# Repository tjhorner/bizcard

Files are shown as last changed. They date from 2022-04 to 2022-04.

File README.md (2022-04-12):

# PCBusiness Card



Hiya! Welcome to the documentation for my... business card? Yep, my business card. Which is also a PCB. Chances are you received one from me and are curious enough to scan the QR code on the back.

In these docs, you'll find information on the specs, how to flash it, which peripherals are onboard, how to do cool stuff with it, and (if you received a bare board) where to source the parts you'll need to assemble it. You'll also find the source KiCad project files for the schematic and board, as well as the source for the firmware that is installed by default. These are open source under CC-BY-SA 4.0 and MIT, so feel free to base your own designs on them.

## Directory Structure

- `docs`: Various documents about the project, including hardware info, flashing instructions, etc.
- `firmware`: Default firmware that ships with the board
- `pcb`: KiCad project files for the PCB

## Quick Start

If you want to check out all this board has to offer...

- Look at the docs for the [default firmware](docs/firmware.md). It goes in detail on what it does, and how you can connect to it to your computer via serial to enjoy the whole experience.
- Come back here to dive into the specs, then try your hand at [writing your own firmware](docs/flashing.md) (if you've programmed an Arduino before, it'll be a piece of cake).

After that, it's up to you! You can solder on some GPIO headers and connect whatever the heck you want and make it your own. Blinky Christmas lights? Sure! Doorbell? Why not! Pacemaker? Ok maybe not that. You have the full power of the RP2040 at your disposal, plus a hefty amount of flash you can use to store anything you want.

## Documentation

- [Bill of Materials](docs/bom.md)
- [Flashing Instructions](docs/flashing.md)
- [Schematic](docs/schematic.pdf)
- [FAQ](docs/faq.md)

## Bare Board Assembly

If you received a bare board, you can find the list of parts you will need (and links to where you can buy them) in the [bill of materials](docs/bom.md). At the moment, this assumes you know how to solder really small surface-mount parts (there are a couple of 0402 parts on there)! So this isn't really a beginner project, unfortunately. I might make a through-hole version in the future (or make the SMD pads bigger, I guess), so that it's easier for beginners, but right now you need to be really good at soldering very precisely.

If, for some reason, you really really want an assembled board, there are services out there that will do it for you. Just Google around for "SMT assembly service" and you'll find one. Or you could just ask me. Let me know what you plan to use it for, and if I have any assembled ones lying around I will gladly send one over for you to tinker with! You know how to reach me :)

## Specs

Here is a summary of the things on the board, but you can find more detailed info below:

- **Microcontroller**: [RP2040](https://www.raspberrypi.com/products/rp2040)
- **Flash**: 16MB [W25Q128JVS](http://www.winbond.com/resource-files/w25q128jv_dtr%20revc%2003272018%20plus.pdf)
- **Clock**: 12MHz [X322512MSB4SI](https://lcsc.com/product-detail/SMD-Crystal-Resonators_Yangxing-Tech-X322512MSB4SI_C9002.html) crystal
- **Connectivity**: USB-C 2.0
- **Peripherals**
  - Piezo Buzzer
  - WS2812B (x4)
  - Reset Button
  - USB Boot Button
  - GPIO Headers

### Microcontroller

At the core of the board is an [RP2040](https://www.raspberrypi.com/products/rp2040/), a microcontroller from the same people who make the Raspberry Pi. It was chosen mostly because I heard of it once and decided it would be cool to include in a project, so there it is! It's relatively cheap, but pretty powerful. It is also extremely well-documented and has lots of community support, making it great to write your own firmware for.

- [RP2040 Datasheet](https://datasheets.raspberrypi.com/rp2040/rp2040-datasheet.pdf)
- [RP2040 Documentation](https://www.raspberrypi.com/documentation/microcontrollers/rp2040.html)
- [Official C/C++ SDK](https://www.raspberrypi.com/documentation/microcontrollers/c_sdk.html)
- [Official MicroPython SDK](https://www.raspberrypi.com/documentation/microcontrollers/micropython.html)

### Flash

The prepopulated boards come with a hefty 16MB of onboard QSPI flash provided by the W25Q128JVS chip, which is recommended by the Raspberry Pi Foundation in their hardware design documentation. This means you can include lots of libraries in your code and not have to worry about running out of space. Plus, this is actually the maximum amount of flash storage the RP2040 supports, so you can utilize it to its full potential.

If you have a bare board and don't want to go with the W25Q128JVS, you can use any QSPI flash you want. There are more details in the [RP2040 datasheet](https://datasheets.raspberrypi.com/rp2040/rp2040-datasheet.pdf#section_ssi), under section 4.10.

- [W25Q128JVS Datasheet](http://www.winbond.com/resource-files/w25q128jv_dtr%20revc%2003272018%20plus.pdf)

### Clock

The clock on the prepopulated boards is a 12MHz crystal. There's not much else to say here!

- [X322512MSB4SI Datasheet](https://datasheet.lcsc.com/lcsc/2103291203_Yangxing-Tech-X322512MSB4SI_C9002.pdf)

### Connectivity

In the top-left corner of the board you will find a USB-C receptacle, chosen simply because I really like USB-C, and it's very commonly used in other devices these days, so I'm sure you will have a cable lying around. Conveniently, the RP2040 actually has USB support built-in, so no additional components were required to get it to work.

### Peripherals

I included some peripherals on board so that it's not entirely boring when you plug it in, and if you want to reflash it with your own firmware you already have some stuff to play with!

#### Piezo Buzzer

The buzzer is connected to GPIO3, and is compatible with the Arduino framework's [tone method](https://www.arduino.cc/reference/en/language/functions/advanced-io/tone/), so it's very easy to write code for.

On the prepopulated boards I used [this buzzer](https://lcsc.com/product-detail/Buzzers_CY-Changzhou-Chaoyin-Elec-Cy-SMD-9019-3040_C968734.html) just because it was the first one from JLCPCB that matched the footprint I used. If you have a bare board, you can use any passive 3V 9x9mm SMD buzzer, like [this one](https://www.digikey.com/en/products/detail/cui-devices/CPT-9019S-SMT-TR/6012432) from Digi-Key.

- [Datasheet](https://datasheet.lcsc.com/lcsc/2012111405_CY-Changzhou-Chaoyin-Elec-Cy-SMD-9019-3040_C968734.pdf)

#### WS2812B (aka NeoPixel)

There are four WS2812B RGB LEDs on the top-right of the board connected to GPIO24 that you can do whatever you want with. The cool thing about these LEDs is that they have a built-in driver chip and you can link them together to control as many as you want from just a single data pin. There are a couple of libraries you can use to drive them, but I like Adafruit's [NeoPixel library](https://github.com/adafruit/Adafruit_NeoPixel).

- [WS2812B Datasheet](https://cdn-shop.adafruit.com/datasheets/WS2812B.pdf)

#### Reset & USB Boot Buttons

These aren't peripherals, per se, but I thought I would include them here anyway.

The reset button can be used to restart the RP2040, and the USB boot button can be held during boot to instruct the RP2040 to mount itself as a mass storage device so you can reflash it.

#### GPIO Headers

Also not really a peripheral, but very useful for connecting your own stuff! These are unpopulated by default to keep the profile small, but if you want to turn the card into basically a fully-fledged RP2040 dev board, you can solder some 2.54mm-pitch headers to the unpopulated pads. [Here](https://www.digikey.com/en/products/detail/adam-tech/PH2-12-UA/9830397) is a 2x6 pin header from Digi-Key that should fit nicely. There's also a [socket version](https://www.digikey.com/en/products/detail/sullins-connector-solutions/PPPC062LFBN-RC/810246) similar to what you would find on an Arduino Uno, if you prefer that.

Once you have soldered the headers, you can go ahead and use the labeled GPIO pins to connect whatever other peripherals you want to the board and make it truly your own. Have fun!

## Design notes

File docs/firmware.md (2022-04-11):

# Default Firmware

The firmware that comes pre-installed on each of the cards does a couple of things:

- Plays "Still Alive" from Portal on the buzzer
- Sets each Neopixel to a random color every time a note from the song plays
- Simulates the terminal-esque end scene from Portal in sync with the song over USB serial

The source for this firmware can be found in the `firmware` directory of the repository.

It utilizes both of the RP2040's cores: core 0 handles the terminal animation and core 1 handles the music. The notes are split up into segments that roughly correspond with verses in the song, and the animation is split up into these same segments to match. At the end of each segment, both cores will wait for their counterpart to finish before continuing. This means that the song will wait for the animation to finish before playing the next segment, and vice versa.

If you want to see the terminal animation in action, the easiest way is to plug the device into your computer, then view the terminal output from [this website](https://googlechromelabs.github.io/serial-terminal/). It uses Web Serial to connect to the device, so there's no installation required. Follow these steps:

1. Go [here](https://googlechromelabs.github.io/serial-terminal/). (Make sure you are using a supported browser. Notably, Firefox does not support the Web Serial API)
2. Click the "Connect" button (make sure the baud rate is set to 115200)
3. Plug in the device
4. Within 5 seconds of plugging it in, select it from the dropdown. It should be named "PCBusinessCard"
5. Enjoy the show!

If you want to view it natively from an actual terminal emulator, you can do that as well, but it's not as simple:

- **macOS**: From a terminal, run the command `screen /dev/cu.usbmodem* 115200` while the device is plugged in
- **Windows**: You can use [PuTTY](https://www.putty.org/) to access the device from a COM port. The baud rate is 115200
- **Linux**: You probably know what you are doing, but you can use the command `screen /dev/ttyUSB* 115200` to get started

I recommend resetting the device then connecting immediately after, this way the terminal is correctly set up. Otherwise, you'll start in the middle of the animation and things will look strange.

Or you can just watch this video, but that's kinda lame (turn up your volume!):

https://user-images.githubusercontent.com/2646487/162366428-906fa74b-1275-4396-9afb-aaf11e48caa4.mp4

## Acknowledgements

Big thanks to these folks for open sourcing their work, which this firmware incorporates much of:

- "Still Alive" MIDI: https://www.vgmusic.com/file/bfae50e09af58a8f4415968b79464346.html
- "Still Alive" terminal version, which I ported to work with Arduino: https://github.com/ivanp7/still-alive
- mcurses, a very slim implementation of ncurses: https://github.com/ChrisMicro/mcurses

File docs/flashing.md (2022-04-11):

# Flashing Instructions

If you want to write your own code to run on the board, you can totally do that! You can write software for the RP2040 in a couple different ways, like the official [C/C++ SDK](https://www.raspberrypi.com/documentation/microcontrollers/c_sdk.html) or [MicroPython](https://www.raspberrypi.com/documentation/microcontrollers/micropython.html). But I prefer to use PlatformIO with the Arduino framework. It's very easy to set up and integrates nicely with VS Code, which I use as my main editor. You can use whatever you like, but I will go over how to set it up with PlatformIO in this guide since that's what the default firmware is built with.

## Building the Default Firmware

Included in this repository is a template for custom firmware, with everything all set up and ready to go specifically for this board.

There are a few prequisites you need before we begin:

- [Visual Studio Code](https://code.visualstudio.com)
- [PlatformIO](https://platformio.org/platformio-ide)
- A USB-C cable

Once you've downloaded all of the above, you should be good to go!

First, let's clone the repo:

```shell
git clone https://github.com/tjhorner/bizcard.git
```

Open the `firmware-template` directory in VS Code. PlatformIO should recognize this is a PIO project and give you several options in the sidebar under the quick access menu (it's the PIO logo -- kinda looks like an ant or alien or something). If you see options like "Build, "Upload", etc. then you should be good to go.

Plug the board into your computer, then press "Upload" from VS Code. After a short while (it needs to download all the dependencies and compile the firmware), it should automatically detect the board and flash it. If not, you may need to press and hold the button labeled "USB", then press "RST" simultaneously. Release both buttons and it should now show up as a drive on your computer. Try uploading again.

Once flashed successfully, you should see `[SUCCESS]` near the end of the terminal output. Ta-da! You're now ready to customize the firmware to fit your needs.

## Customizing the Firmware

The firmware template is designed to be used as a jumping-off point for custom firmware; it already includes examples of how to use the onboard peripherals like the piezo buzzer and Neopixels. It also uses the Arduino framework, providing a familiar way to access the hardware and GPIO pins. Take a look at `main.cpp` -- that should be enough to get you started!

If you followed the section above, flashing is exactly the same. Just re-run the upload after you've made your modifications. If you need any help, well... you know how to reach me :)

## Other Methods

There are other ways to write and flash firmware for RP2040-based boards like this one; for example, anything that supports the Raspberry Pi Pico should work. But note that you may run into strange quirks, because the Pico uses some of the RP2040 pins for internal functions, and the compiled firmware assumes these.

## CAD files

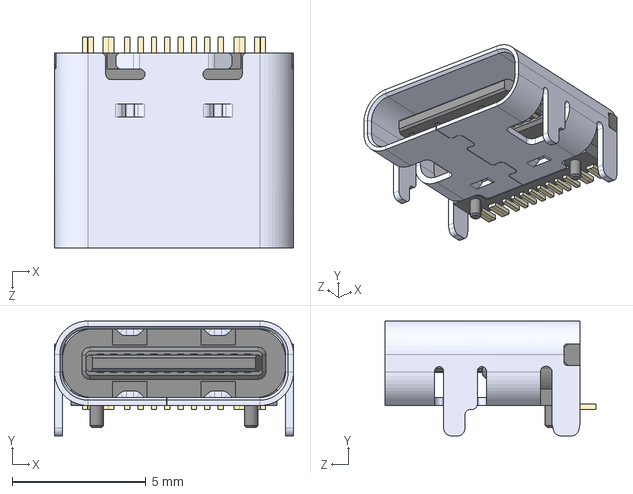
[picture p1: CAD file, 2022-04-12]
pcb/footprints/TYPE-C-31-M-12--3DModel-STEP-56544.STEP
8.94 x 4.30 x 7.90 mm

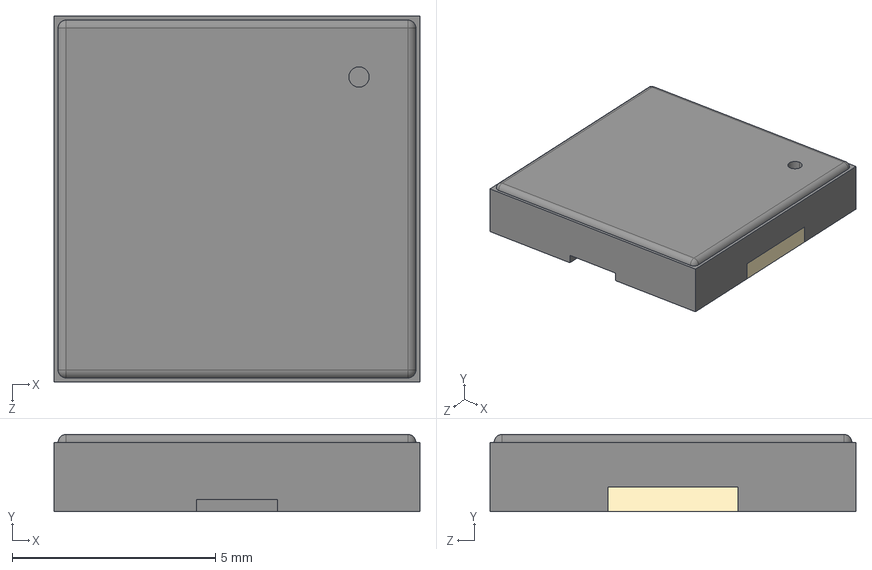
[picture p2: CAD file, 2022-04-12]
pcb/footprints/PKMCS0909E4000-R1--3DModel-STEP-56544.STEP
9.00 x 1.90 x 9.00 mm

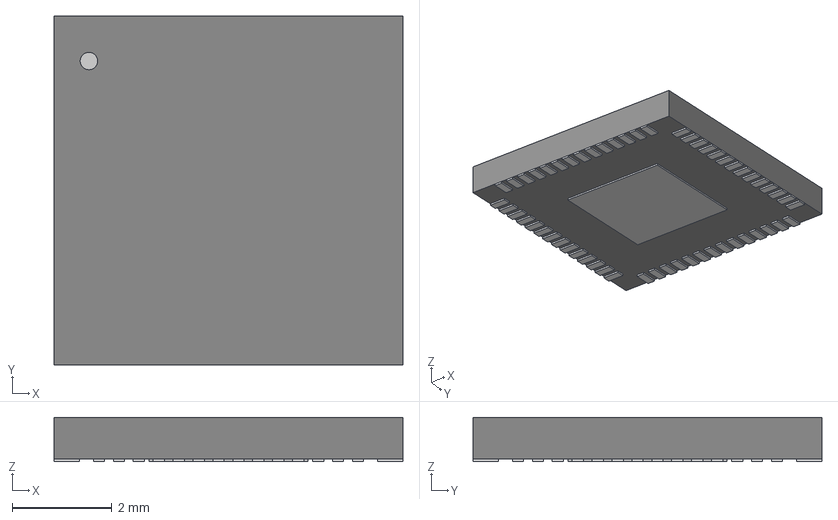
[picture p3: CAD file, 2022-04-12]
pcb/footprints/IC57_RP2040.step
7.01 x 7.01 x 0.892 mm

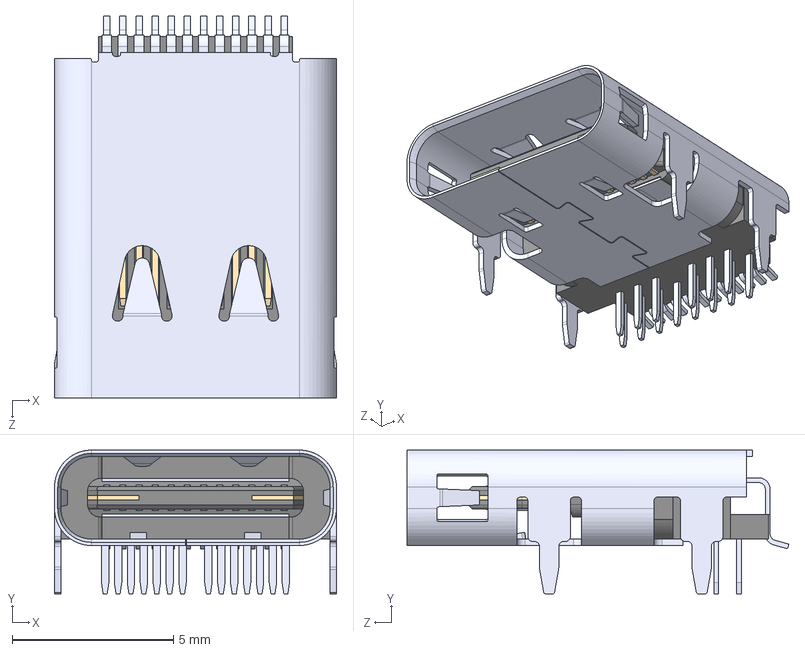
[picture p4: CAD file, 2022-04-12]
pcb/footprints/SS-52400-002--3DModel-STEP-56544.STEP
8.74 x 4.46 x 11.8 mm

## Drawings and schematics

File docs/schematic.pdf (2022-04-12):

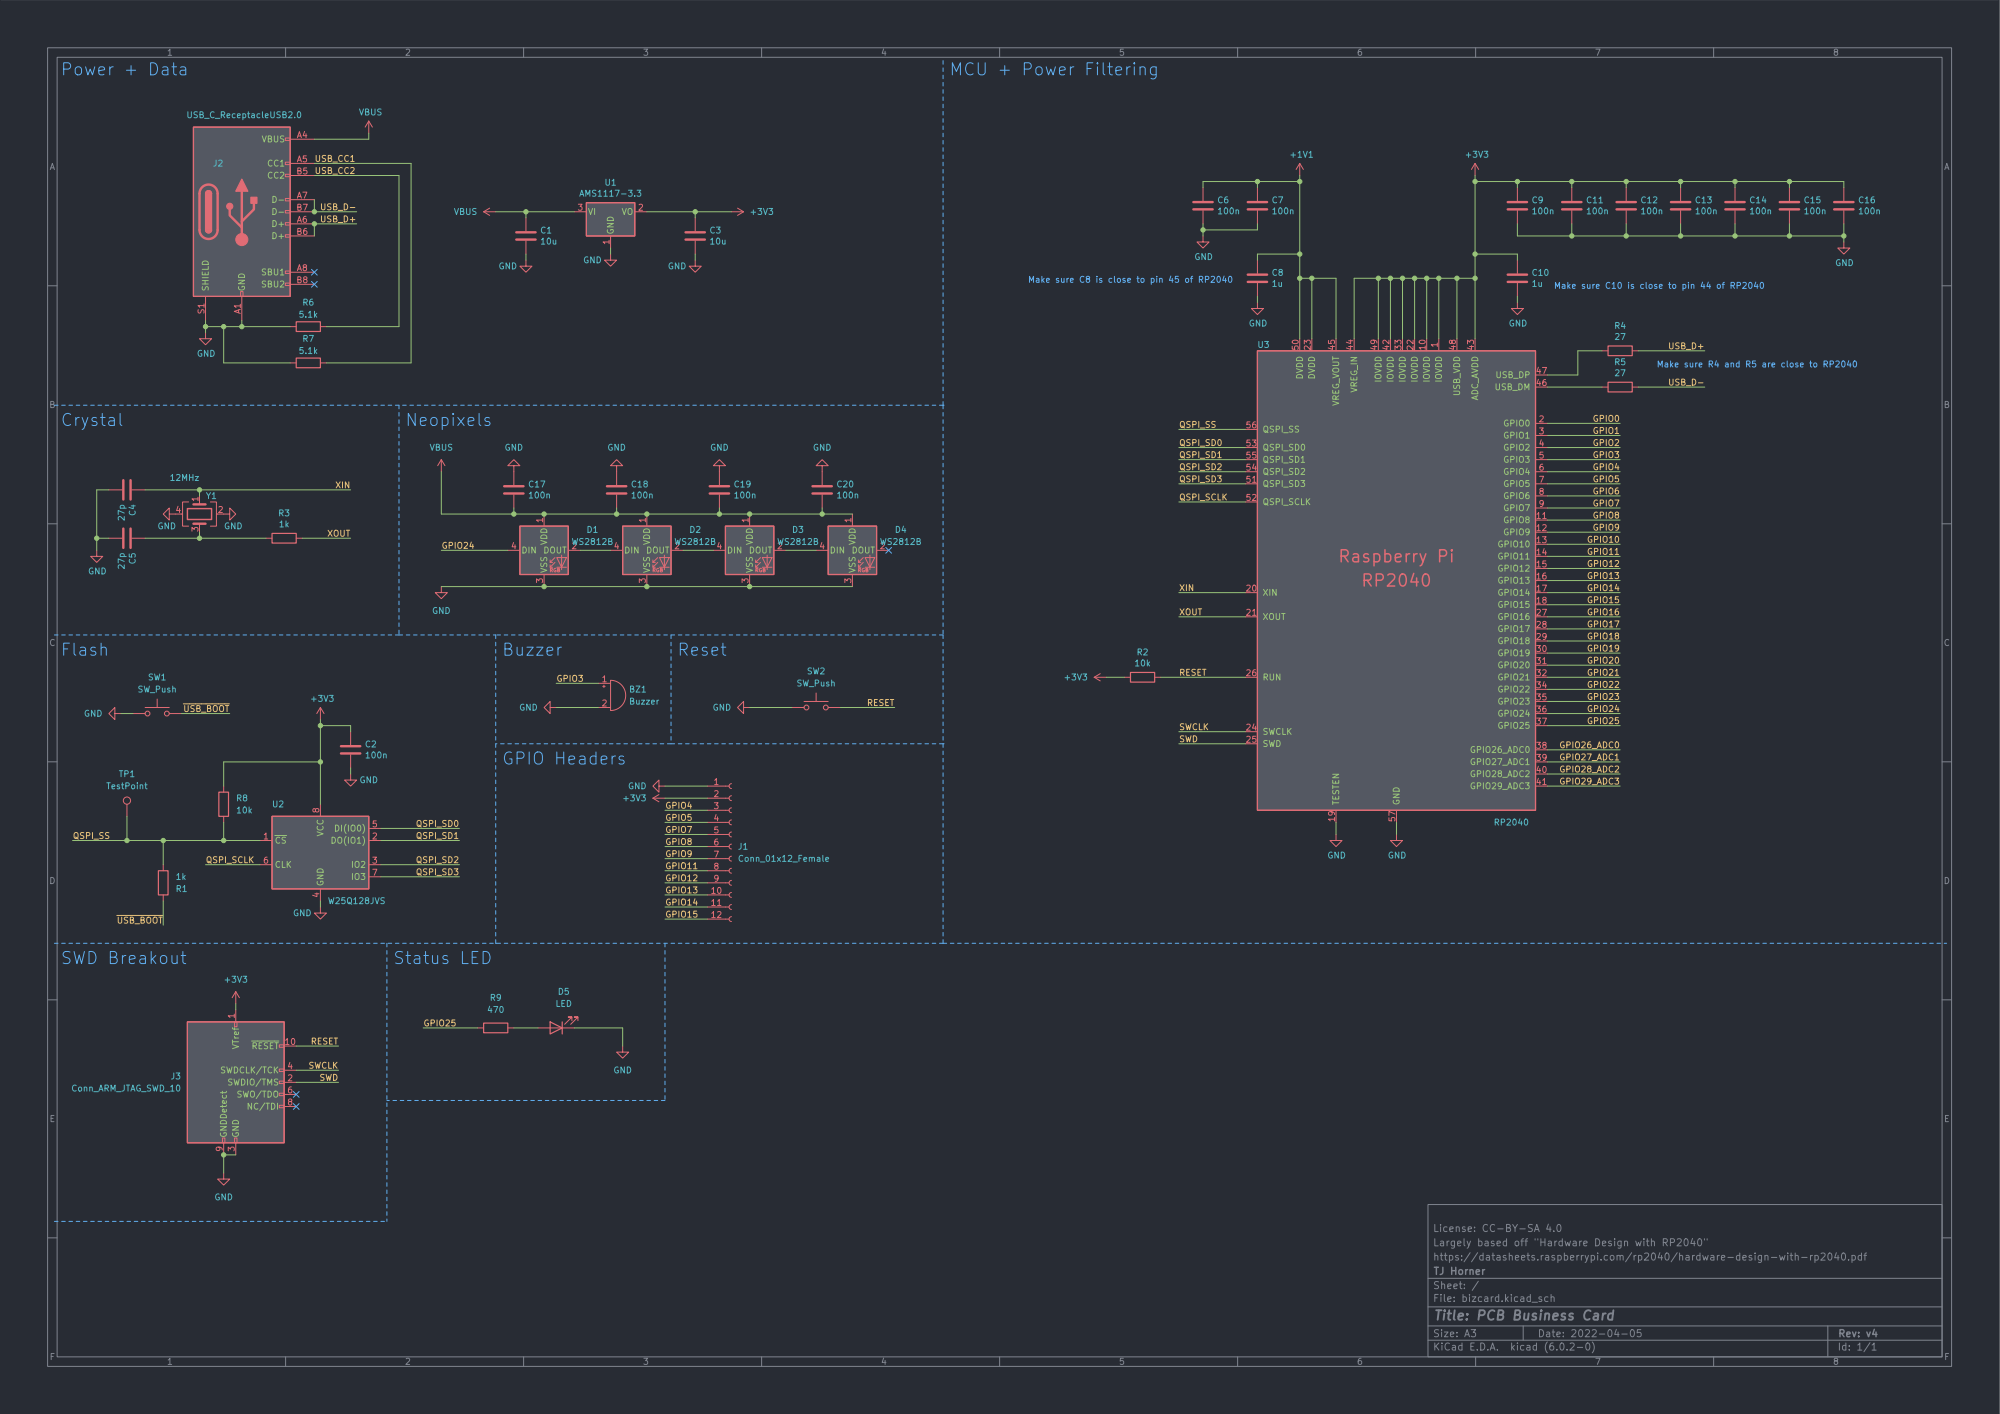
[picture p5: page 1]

Make sure R4 and R5 are close to RP2040 Power + Data

Largely based off "Hardware Design with RP2040" License: CC-BY-SA 4.0 Raspberry Pi

Make sure C8 is close to pin 45 of RP2040

Make sure C10 is close to pin 44 of RP2040

1 IOVDD 10 GPIO8 11 GPIO9 12 GPIO10 13 GPIO11 14 GPIO12 15 GPIO13 16 GPIO14 17 GPIO15 18 TESTEN 19 GPIO0 2 XIN 20 XOUT 21 IOVDD 22 DVDD 23 SWCLK 24 SWD 25 RUN 26 GPIO16 27 GPIO17 28 GPIO18 29 GPIO1 3 GPIO19 30 GPIO20 31 GPIO21 32 IOVDD 33 GPIO22 34 GPIO23 35 GPIO24 36 GPIO25 37 GPIO26_ADC0 38 GPIO27_ADC1 39 GPIO2 4 GPIO28_ADC2 40 GPIO29_ADC3 41 IOVDD 42 ADC_AVDD 43 VREG_IN 44 VREG_VOUT 45 USB_DM 46 USB_DP 47 USB_VDD 48 IOVDD 49 GPIO3 5 DVDD 50 QSPI_SD3 51 QSPI_SCLK 52 QSPI_SD0 53 QSPI_SD2 54 QSPI_SD1 55 QSPI_SS 56 GND 57 GPIO4 6 GPIO5 7 GPIO6 8 GPIO7 9 U3 RP2040

3 SWDCLK/TCK 4 SWO/TDO 6 NC/TDI 8 GNDDetect 9

File: bizcard.kicad_sch Sheet: / TJ Horner https://datasheets.raspberrypi.com/rp2040/hardware-design-with-rp2040.pdf

Id: 1/1 Title: PCB Business Card

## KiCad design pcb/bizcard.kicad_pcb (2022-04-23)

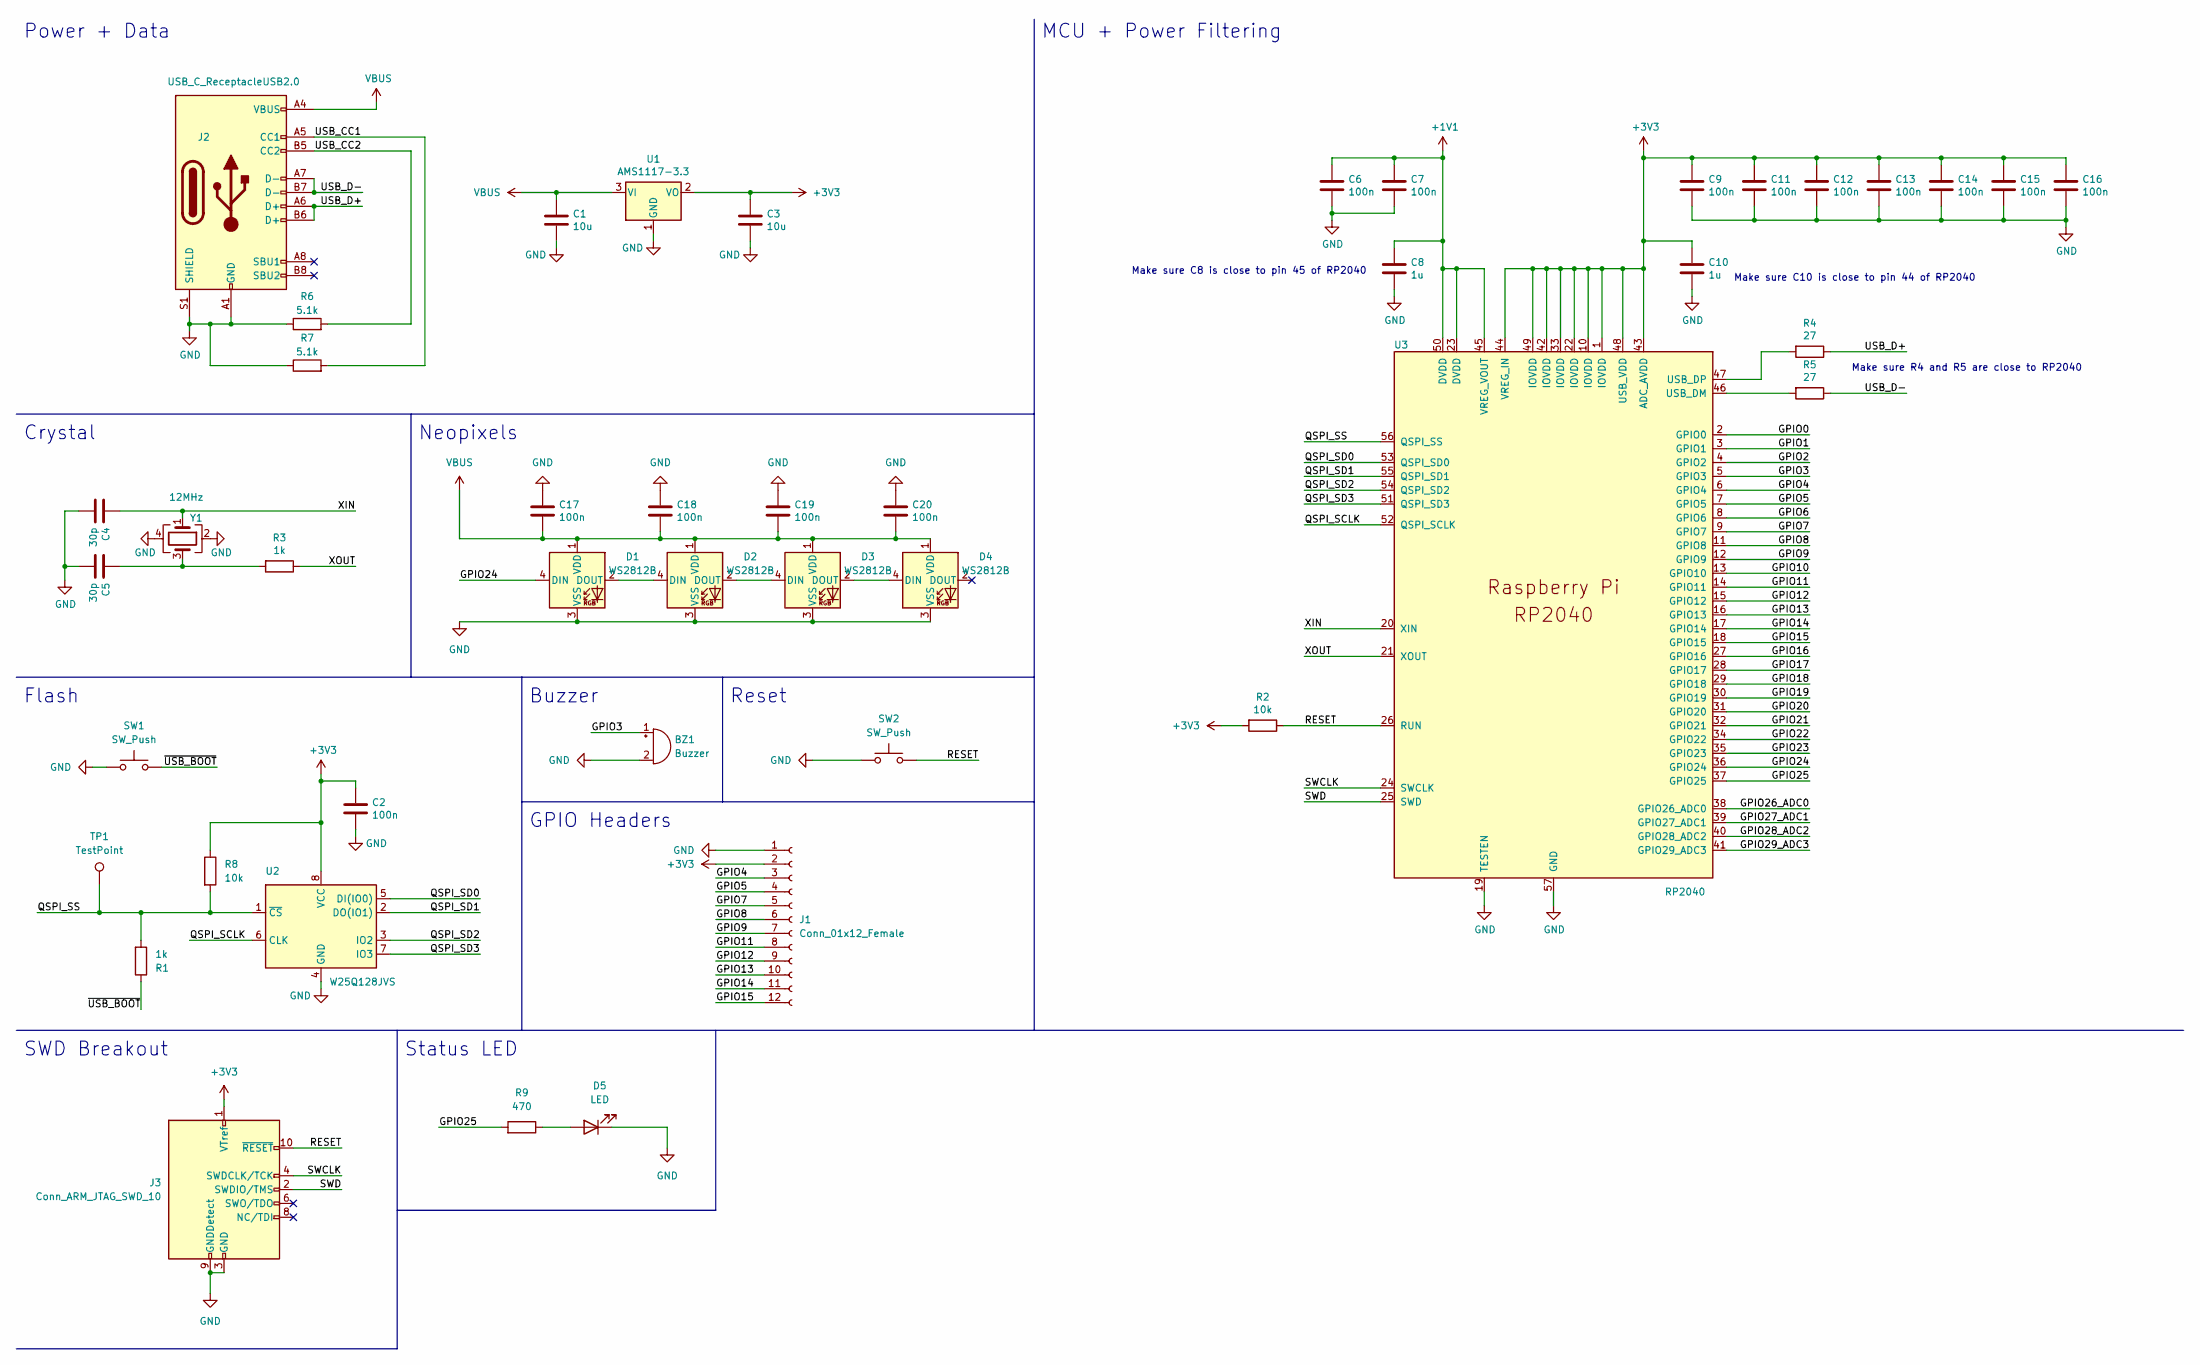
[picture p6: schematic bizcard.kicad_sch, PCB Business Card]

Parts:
BZ1: Buzzer; Buzzer_CUI_CPT-9019S-SMT; LCSC C391035
C1, C3: 10u; C_0402_1005Metric; LCSC C15525
C2, C6, C7, C9, C11, C12, C13, C14, C15, C16, C17, C18, C19, C20: 100n; C_0402_1005Metric; LCSC C1525
C4, C5: 30p; C_0402_1005Metric; LCSC C1570
C8, C10: 1u; C_0402_1005Metric; LCSC C52923
D1, D2, D3, D4: WS2812B; LED_WS2812B_PLCC4_5.0x5.0mm_P3.2mm; LCSC C2761795
D5: LED; LED_0603_1608Metric; LCSC C72043
J1: Conn_01x12_Female; PinSocket_2x06_P2.54mm_Vertical
J2: USB_C_ReceptacleUSB2.0; USB_C_Receptacle_Palconn_UTC16-G; LCSC C165948
J3: Conn_ARM_JTAG_SWD_10; PinHeader_2x05_P1.27mm_Vertical_SMD
R1, R3: 1k; R_0402_1005Metric; LCSC C11702
R2, R8: 10k; R_0402_1005Metric; LCSC C25744
R4, R5: 27; R_0603_1608Metric; LCSC C25190
R6, R7: 5.1k; R_0402_1005Metric; LCSC C25905
R9: 470; R_0402_1005Metric; LCSC C25117
SW1, SW2: SW_Push; SW_SPST_TL3342; PARTREV A0; LCSC C318884
TP1: TestPoint; TestPoint_Pad_D2.5mm
U1: AMS1117-3.3; SOT-223-3_TabPin2; LCSC C6186
U2: W25Q128JVS; SOIC-8_5.23x5.23mm_P1.27mm; LCSC C97521
U3: RP2040; RP2040-QFN-56; LCSC C2040
Y1: 12MHz; Crystal_SMD_3225-4Pin_3.2x2.5mm; LCSC C9002

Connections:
+1V1: C6.1, C7.1, C8.1, U3.23 (DVDD), U3.45 (VREG_VOUT), U3.50 (DVDD)
+3V3: C2.1, C3.1, C9.1, C10.1, C11.1, C12.1, C13.1, C14.1, C15.1, C16.1, J1.2, J3.1 (VTref), R2.2, R8.1, U1.2 (VO), U2.8 (VCC), U3.1 (IOVDD), U3.10 (IOVDD), U3.22 (IOVDD), U3.33 (IOVDD), U3.42 (IOVDD), U3.43 (ADC_AVDD), U3.44 (VREG_IN), U3.48 (USB_VDD), U3.49 (IOVDD)
/GPIO0: U3.2 (GPIO0)
/GPIO1: U3.3 (GPIO1)
/GPIO2: U3.4 (GPIO2)
/GPIO3: BZ1.1 (-), U3.5 (GPIO3)
/GPIO4: J1.3, U3.6 (GPIO4)
/GPIO5: J1.4, U3.7 (GPIO5)
/GPIO6: U3.8 (GPIO6)
/GPIO7: J1.5, U3.9 (GPIO7)
/GPIO8: J1.6, U3.11 (GPIO8)
/GPIO9: J1.7, U3.12 (GPIO9)
/GPIO10: U3.13 (GPIO10)
/GPIO11: J1.8, U3.14 (GPIO11)
/GPIO12: J1.9, U3.15 (GPIO12)
/GPIO13: J1.10, U3.16 (GPIO13)
/GPIO14: J1.11, U3.17 (GPIO14)
/GPIO15: J1.12, U3.18 (GPIO15)
/GPIO16: U3.27 (GPIO16)
/GPIO17: U3.28 (GPIO17)
/GPIO18: U3.29 (GPIO18)
/GPIO19: U3.30 (GPIO19)
/GPIO20: U3.31 (GPIO20)
/GPIO21: U3.32 (GPIO21)
/GPIO22: U3.34 (GPIO22)
/GPIO23: U3.35 (GPIO23)
/GPIO24: D1.4 (DIN), U3.36 (GPIO24)
/GPIO25: R9.2, U3.37 (GPIO25)
/GPIO26_ADC0: U3.38 (GPIO26_ADC0)
/GPIO27_ADC1: U3.39 (GPIO27_ADC1)
/GPIO28_ADC2: U3.40 (GPIO28_ADC2)
/GPIO29_ADC3: U3.41 (GPIO29_ADC3)
/QSPI_SCLK: U2.6 (CLK), U3.52 (QSPI_SCLK)
/QSPI_SD0: U2.5 (DI(IO0)), U3.53 (QSPI_SD0)
/QSPI_SD1: U2.2 (DO(IO1)), U3.55 (QSPI_SD1)
/QSPI_SD2: U2.3 (IO2), U3.54 (QSPI_SD2)
/QSPI_SD3: U2.7 (IO3), U3.51 (QSPI_SD3)
/QSPI_SS: R1.2, R8.2, TP1.1, U2.1 (~CS), U3.56 (QSPI_SS)
/RESET: J3.10 (~RESET), R2.1, SW2.2, U3.26 (RUN)
/SWCLK: J3.4 (SWDCLK/TCK), U3.24 (SWCLK)
/SWD: J3.2 (SWDIO/TMS), U3.25 (SWD)
/USB_CC1: J2.A5 (CC1), R7.2
/USB_CC2: J2.B5 (CC2), R6.2
/USB_D+: J2.A6 (D+), J2.B6 (D+), R4.1
/USB_D-: J2.A7 (D-), J2.B7 (D-), R5.1
/XIN: C4.1, U3.20 (XIN), Y1.1
/XOUT: R3.1, U3.21 (XOUT)
/~USB_BOOT: R1.1, SW1.2
GND: BZ1.2 (+), C1.2, C2.2, C3.2, C4.2, C5.2, C6.2, C7.2, C8.2, C9.2, C10.2, C11.2, C12.2, C13.2, C14.2, C15.2, C16.2, C17.1, C18.1, C19.1, C20.1, D1.3 (VSS), D2.3 (VSS), D3.3 (VSS), D4.3 (VSS), D5.1 (K), J1.1, J2.A1 (GND), J2.A12 (GND), J2.B1 (GND), J2.B12 (GND), J2.S1 (SHIELD), J3.3 (GND), J3.5 (GND), J3.9 (GNDDetect), R6.1, R7.1, SW1.1, SW2.1, U1.1 (GND), U2.4 (GND), U3.19 (TESTEN), U3.57 (GND), Y1.2, Y1.4
unnamed: C5.1, R3.2, Y1.3
unnamed: D1.2 (DOUT), D2.4 (DIN)
unnamed: D2.2 (DOUT), D3.4 (DIN)
unnamed: D3.2 (DOUT), D4.4 (DIN)
unnamed: D5.2 (A), R9.1
unnamed: R4.2, U3.47 (USB_DP)
unnamed: R5.2, U3.46 (USB_DM)
VBUS: C1.1, C17.2, C18.2, C19.2, C20.2, D1.1 (VDD), D2.1 (VDD), D3.1 (VDD), D4.1 (VDD), J2.A4 (VBUS), J2.A9 (VBUS), J2.B4 (VBUS), J2.B9 (VBUS), U1.3 (VI)

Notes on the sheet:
Status LED
Make sure C8 is close to pin 45 of RP2040
Neopixels
MCU + Power Filtering
Power + Data
Reset
SWD Breakout
Buzzer
Make sure C10 is close to pin 44 of RP2040
GPIO Headers
Crystal
Make sure R4 and R5 are close to RP2040
Flash

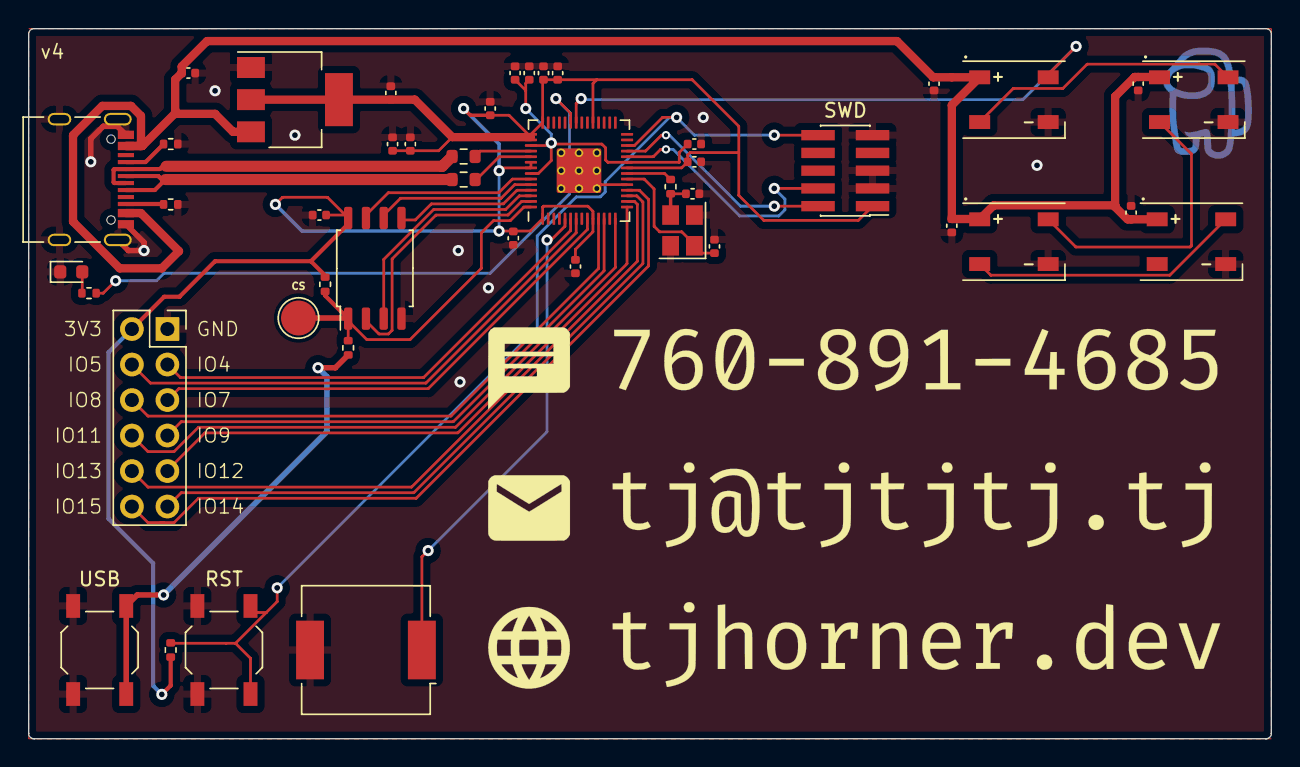
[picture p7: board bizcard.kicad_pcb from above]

Board: 2 copper layers, 88.9 x 50.8 mm, 49 parts (0 on the bottom side), 40 nets.

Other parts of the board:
Ref**: Val**; info
Ref**#2: Val**; amongy
Ref**#3: Val**; qrcode_smaller
Ref**#4: Val**; name_smaller

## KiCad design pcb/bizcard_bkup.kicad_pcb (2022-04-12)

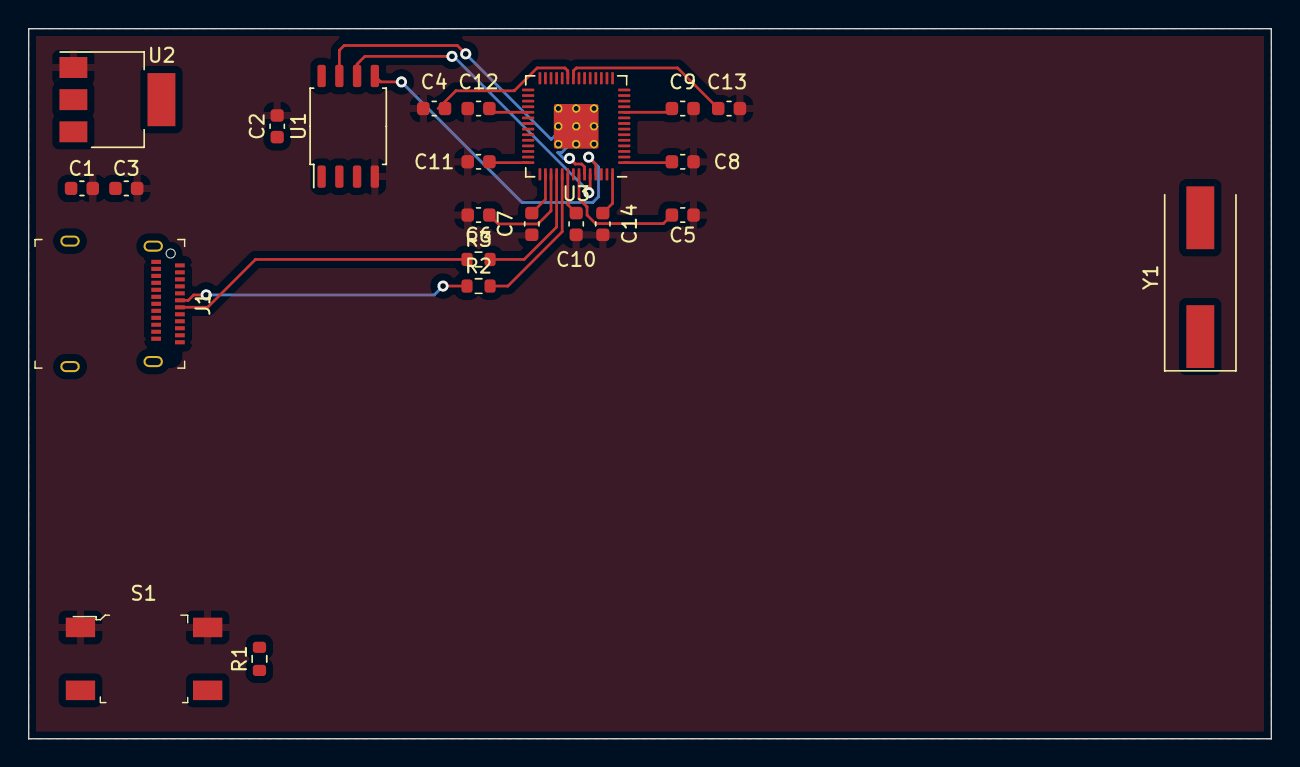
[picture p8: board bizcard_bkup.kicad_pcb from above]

Board: 2 copper layers, 88.9 x 50.8 mm, 25 parts (0 on the bottom side), 16 nets.

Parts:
C1, C3: 10uF; C_0603_1608Metric
C2, C4, C5, C8, C9, C10, C11, C12, C13, C14: 100nF; C_0603_1608Metric
C6, C7: 1uF; C_0603_1608Metric
J1: USB_C_Receptacle; USB-C_Female_12401X
R1: 1k; R_0603_1608Metric
R2, R3: 27.4; R_0603_1608Metric
Ref**: Val**; name
Ref**#2: Val**; info
S1: FSM4JSMATR; Switch_Tactile_SMD_6x6mm
U1: W25Q128JVS; SOIC-8_5.23x5.23mm_P1.27mm
U2: NCP1117-3.3_SOT223; SOT-223-3_TabPin2
U3: RP2040; RP2040-QFN-56
Y1: ABLS-12.000MHZ-B4-T; Crystal_SMD_HC49-SD

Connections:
+1V1: C4.2, C5.2, C6.1, U3.23 (DVDD), U3.45 (VREG_VOUT), U3.50 (DVDD)
+3V3: C2.1, C3.1, C7.1, C8.1, C9.1, C10.1, C11.1, C12.1, C13.1, C14.1, R1.2, U1.1 (~CS), U1.8 (VCC), U2.2 (VO), U3.1 (IOVDD), U3.10 (IOVDD), U3.22 (IOVDD), U3.33 (IOVDD), U3.42 (IOVDD), U3.43 (ADC_AVDD), U3.44 (VREG_IN), U3.48 (USB_VDD), U3.49 (IOVDD), U3.56 (QSPI_SS)
/QSPI_CLK: U1.6 (CLK), U3.52 (QSPI_SCLK)
/USB_D+: J1.A6 (D+), J1.B6 (D+), R2.1
/USB_D-: J1.A7 (D-), J1.B7 (D-), R3.1
/XIN: U3.20 (XIN), Y1.1
/XOUT: U3.21 (XOUT), Y1.2
GND: C1.2, C2.2, C3.2, C4.1, C5.1, C6.2, C7.2, C8.2, C9.2, C10.2, C11.2, C12.2, C13.2, C14.2, J1.A1 (GND), J1.A12 (GND), J1.B1 (GND), J1.B12 (GND), S1.1, S1.2, U1.4 (GND), U2.1 (GND)
unnamed: R1.1, S1.3, S1.4
unnamed: R2.2, U3.47 (USB_DP)
unnamed: R3.2, U3.46 (USB_DM)
unnamed: U1.2 (DO(IO1)), U3.55 (QSPI_SD1)
unnamed: U1.3 (IO2), U3.54 (QSPI_SD2)
unnamed: U1.5 (DI(IO0)), U3.53 (QSPI_SD0)
unnamed: U1.7 (IO3), U3.51 (QSPI_SD3)
VBUS: C1.1, J1.A4 (VBUS), J1.A9 (VBUS), J1.B4 (VBUS), J1.B9 (VBUS), U2.3 (VI)

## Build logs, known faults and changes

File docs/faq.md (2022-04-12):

# FAQ

## Why?

I've always been fascinated by unique business cards, and I've seen a couple of PCB business cards in the past ([here](https://www.youtube.com/watch?v=zHVrY_xLM3c) is a really cool one). So I thought it would be cool to make one of my own, and hopefully make a great first impression to whoever I give them to. It was also an excellent learning experience in electronics design, giving me knowledge that I can use in future projects.

## There's a "v2" or "v3" in the top-left of the board, what does it mean?

This is, as you probably guessed, how I version the different revisions of the board.

### v1

While there was technically a v1 board, it wasn't labelled as such and was never distributed to anyone. I made a silly mistake in the design which rendered it totally inoperable. So all it does is sit there and look cool.

### v2

If you find yourself in possession of a v2 board, congratulations! There were only ever 5 of these made, and only 2 of them were preassembled. This version has a defect where the decoupling capacitor for the Neopixels were connected inline with the circuit instead of to ground. You may notice a solder bridge where the capacitor is supposed to be.

### v3

- The decoupling capacitor for the Neopixels is now connected to ground
- There is now one decoupling capacitor for each Neopixel
- CC1 and CC2 on the USB connector are now connected to ground with a 5.1k resistor in between
- There's a 5V voltage regulator for the Neopixels, because VBUS can actually be higher than 5V
- The silkscreen for the info on the back was resized to not overlap with the pads
- Added test pads for QSPI_SS, VBUS, and USB+/-
- Changed the buttons to both save on cost and make the profile smaller

### v4

- Removed 5V regulator, because I am dumb
- Added optional SWD headers for debugging (this will work well: https://www.adafruit.com/product/752)
- Neopixel GPIO pin changed to 24 (from 25)
- Added built-in LED on GPIO 25
  - This change was made because most other RP2040 boards have an LED on this pin, and it's where the Arduino framework expects it to be
- Removed reference designators from silkscreen to make it look cleaner
- Swapped GND and 3V3 on the headers, because it makes more sense that GND is pin 1
- KiCad DRC rules modified to use JLCPCB design capabilities
- Other minor design changes

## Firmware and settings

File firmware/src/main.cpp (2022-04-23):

#ifndef OEMTEST

#include "gfx.h"
#include "notes.h"
#include "main.h"

// mcurses helpers
void Arduino_putchar(uint8_t c)
{
  Serial.write(c);
}

char Arduino_getchar()
{
  while (!Serial.available());
  return Serial.read();
}

// Core 0 entrypoint (handles graphics)
void setup()
{
#if BIZCARD_V4
  pinMode(LED_BUILTIN, OUTPUT);
  digitalWrite(LED_BUILTIN, HIGH);
#endif

  setFunction_putchar(Arduino_putchar);
  setFunction_getchar(Arduino_getchar);
}

void loop()
{
  // Give user some time to open serial connection
  delay(5000);
  gfx::main();
}

// Core 1 entrypoint (handles sound)
void setup1()
{
  notes::setup();
}

void loop1()
{
  // Indicate to core 0 that we're ready to continue animation
  rp2040.fifo.push(1);

  // Wait for core 0 to indicate that it's time to play the next segment
  rp2040.fifo.pop();

  notes::playNextSegment();
}

#endif

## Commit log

2022-04-12 and there we go
    [IC57_RP2040.step, PKMCS0909E4000-R1--3DModel-STEP-56544.STEP, SS-52400-002--3DModel-STEP-56544.STEP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]
2022-04-12 fix schematic
    [bizcard.kicad_sch]
2022-04-23 slight updates
    [bizcard.kicad_pcb]
